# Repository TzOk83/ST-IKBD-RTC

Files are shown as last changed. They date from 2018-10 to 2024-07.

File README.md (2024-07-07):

# ST-IKBD-RTC

Arduino Nano / ATMega328PU + DS3231 based RTC injector for Atari STf/e.

This module can be used to overcome the ST's IKBD real time clock/calendar limitation to year 1999 and lack of battery back-up. This simple circuit can be plugged between the motherboard and keyboard, and is completely transparent for the user. It emulates original IKBD clock, so doesn't need any additional drivers nor software. It intercepts communication between keyboard and motherboard, and when clock/calendar related commands are detected it masks them out and supplies own replies. It causes only a minor delay (1.3ms) for keyboard/joystick/mouse signals. As both TOS and Atari Control Panel suprisingly are Y2K compilant (due to kind of bug in bin<->bcd conversion routines), no software patches are required.

* on STf(m) with TOS 1.00 - 1.04 it works using ST Control Panel (CONTROL.ACC), Panel is used both for synchronizing ST Clock with IKBD Clock on reboot and for manually adjusting the clock,
* on STe with TOS 1.06/1.62 using STE_FIX.PRG and STE Control Panel (CONTROL.ACC), STE_FIX is used for synchronizing ST Clock with IKBD Clock on reboot, Panel is required only for manually adjusting the clock,
* on STe with TOS 2.06 it works using XControl (XCONTROL.ACC), ST Clock with IKBD Clock synchronization on reboot is done by TOS itself, XControl is required only for manually adjusting the clock.

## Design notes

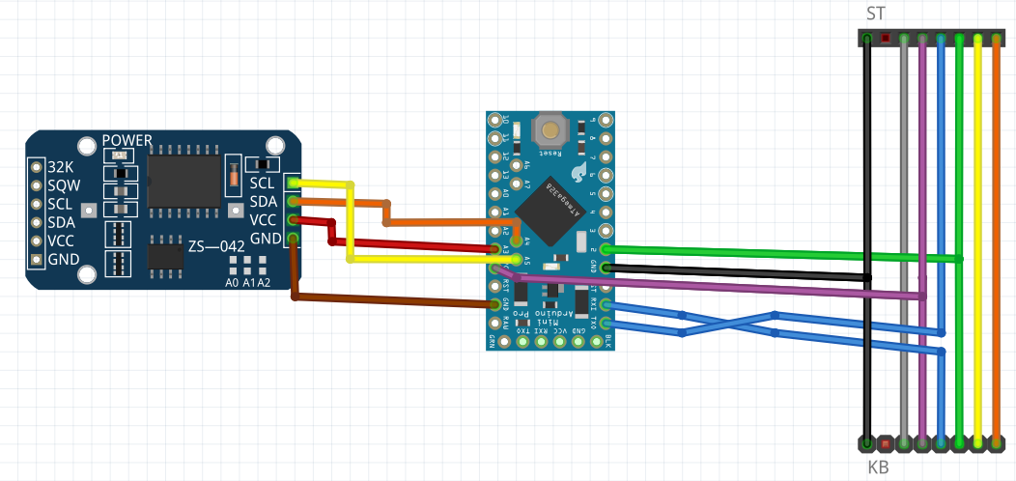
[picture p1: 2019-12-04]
st_ikbd_rtc.png

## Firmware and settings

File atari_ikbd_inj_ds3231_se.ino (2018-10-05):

/******************************************************************
 Created with PROGRAMINO IDE for Arduino - 06.08.2018 15:23:03
 Project     : Atari ST IKBD clock injector with DS3231 RTC
 Libraries   : SoftwareSerial, Wire
 Author      : TzOk
 Description : ARD_RX0 from KB_5, ARD_TX1 to ST_5,
               ARD_D5 from/to KB/ST_6, ARD_A3(17) to DS3231 Vcc.
******************************************************************/

#include <SoftwareSerial.h>
#include <Wire.h>

#define DS3231_ADDRESS (0x68)
#define DS3231_REG_TIME (0x00)

SoftwareSerial Ctrl(5,6);

byte cmd;
byte inj = 255;
byte dsDate[7];
byte stDate[7] = {0x00, 0x00, 0x00, 0x00, 0x00, 0x00, 0xFC};
//                  ss,   mm,   hh,   DD,   MM,   YY

void setup()
{ 
  pinMode(17, OUTPUT);
  digitalWrite(17, HIGH); // Power for DS3231
  Serial.begin(7812);
  Serial.setTimeout(10);
  Ctrl.begin(7812);
  Ctrl.listen();
  Wire.begin();
}

void loop()
{
  if (Ctrl.available())
  {
    cmd = Ctrl.read();
    if (cmd == 0x1C) // Read RTC
    {
      Wire.beginTransmission(DS3231_ADDRESS);
      Wire.write(DS3231_REG_TIME);
      Wire.endTransmission();
      Wire.requestFrom(DS3231_ADDRESS, 7);
      while(!Wire.available()) {};
      for (byte i = 6; i < 255; i--)
      {
        dsDate[i] = Wire.read();
      }
      stDate[5] = (dsDate[1] & 0x80) ? dsDate[0] + 0xA0 : dsDate[0]; // YY : if CENTURY bit is SET => stDate = dsDate + 100
      stDate[4] = dsDate[1] & 0x1F; // MM
      stDate[3] = dsDate[2]; // DD
      stDate[2] = dsDate[4] & 0x3F; // hh
      stDate[1] = dsDate[5]; // mm
      stDate[0] = dsDate[6]; // ss
      inj = 6;
    }
    else if (cmd == 0x1B) // Set RTC
    {
      for (byte i = 5; i < 255; i--)
      {
        while(!Ctrl.available()) {};
        stDate[i] = Ctrl.read();
      }
      dsDate[0] = (stDate[5] < 0xA0) ? stDate[5] : stDate[5] - 0xA0; // YY : if stDate > 99 => dsDate = stDate - 100
      dsDate[1] = (stDate[5] < 0xA0) ? stDate[4] : stDate[4] + 0x80; // MM : if stDate > 99 => set CENTURY bit
      dsDate[2] = stDate[3]; // DD
      dsDate[3] = 0x01; // Day of Week : don't care, any valid value 1-7 will be ok
      dsDate[4] = stDate[2]; // hh
      dsDate[5] = stDate[1]; // mm
      dsDate[6] = stDate[0]; // ss
      Wire.beginTransmission(DS3231_ADDRESS);
      Wire.write(DS3231_REG_TIME);
      for (byte i = 6; i < 255; i--)
      {
        Wire.write(dsDate[i]);
      }
      Wire.endTransmission();
    }
  }
}

void serialEvent() {
  if (inj == 255)
    Serial.write(Serial.read());
  else
  {
    Serial.read();
    Serial.write(stDate[inj--]);
  }
}
